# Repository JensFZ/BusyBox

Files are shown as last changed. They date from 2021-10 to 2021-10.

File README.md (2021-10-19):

# BusyBox

In diesen Projekt geht es darum, dass man einen Status einer Website abfragt und, je nach rückgabe, eine grüne oder rote LED Schaltet.

der Web API Code wird demnächst auch hier noch hochgeladen

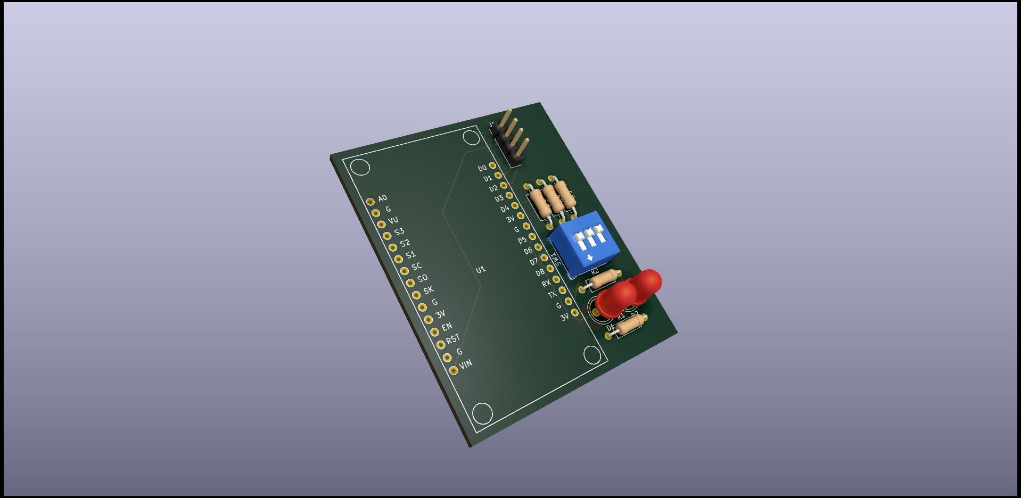
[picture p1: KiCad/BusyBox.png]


## Einrichtung Arduino IDE

- zusützliche Boardverwalter URL: http://arduino.esp8266.com/stable/package_esp8266com_index.json
- über den Boardverwalter nun das Board "esp8266" suchen und installieren
- Als Board nun über "Werkzeuge" -> "Board" -> "ESP8266 Boards" -> "NodeMCU 1.0 (ESP-12E Module)" auswählen
- Uploadspeed auf 115200 stellen
- Port auf den entsprechenden COM Port stellen

## Verwendete Hardware
- 1x NodeMCU Lua Amica Modul V2 ESP8266 ESP-12F
- 1x LED Green
- 1x LED Red
- 1x DIP-Switch 2 Slide
- 5x 1k Wiederstand
- optional LCD 16x2 i2c

## Contributing
Pull requests sind wilkommen. Bei größeren Änderungen eröffnen Sie bitte zunächst ein Issue, um zu besprechen, was Sie ändern möchten.

## License
[MIT](https://choosealicense.com/licenses/mit/)

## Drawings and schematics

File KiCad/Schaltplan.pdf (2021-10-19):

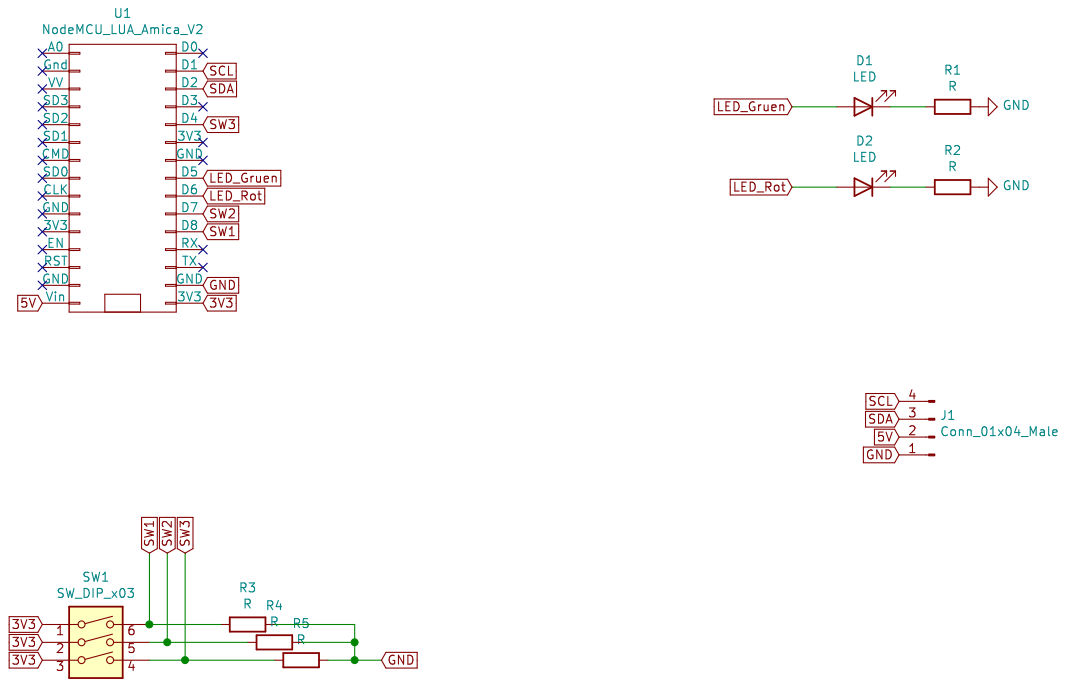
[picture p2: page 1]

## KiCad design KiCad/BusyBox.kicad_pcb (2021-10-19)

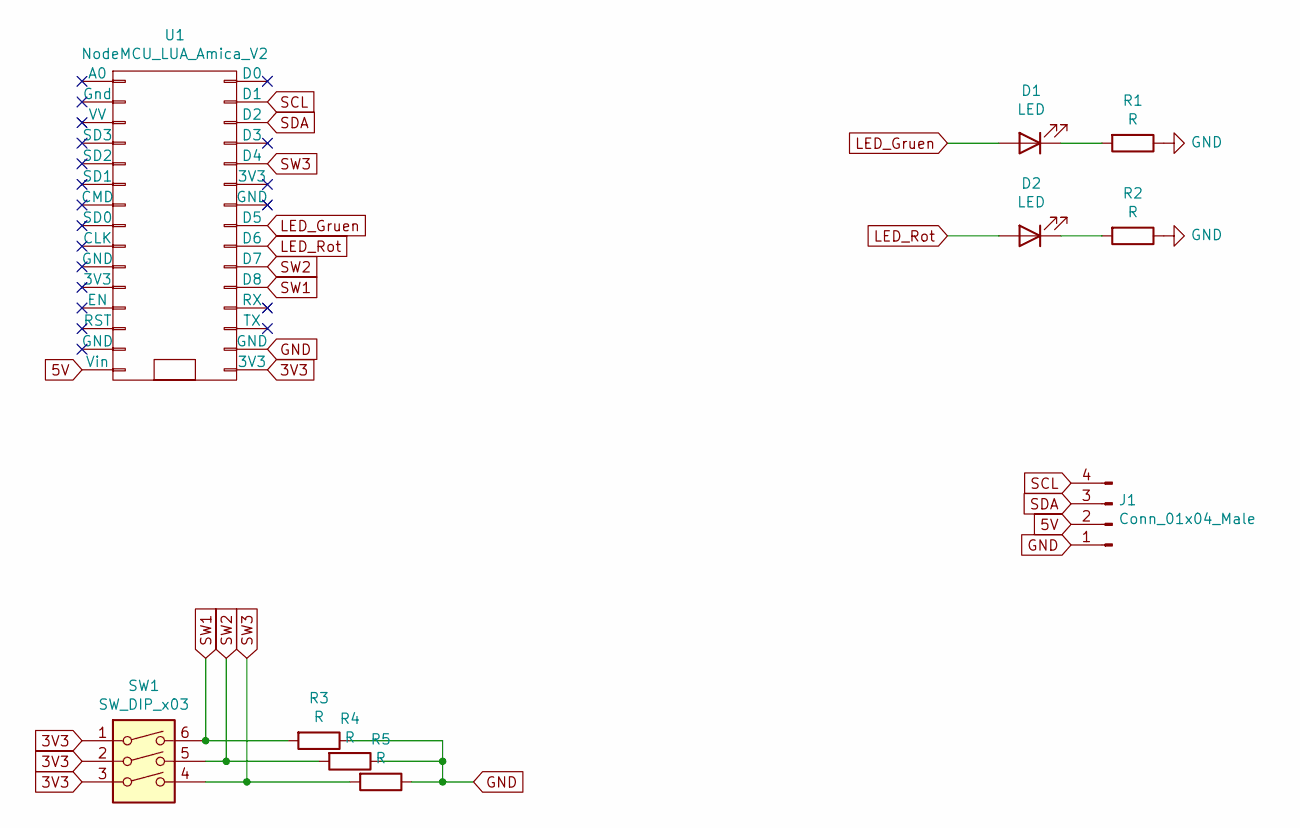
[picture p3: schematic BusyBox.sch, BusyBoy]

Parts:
D1, D2: LED; LED_D5.0mm
J1: Conn_01x04_Male; PinHeader_1x04_P2.54mm_Vertical
R1, R2, R3, R4, R5: R; R_Axial_DIN0207_L6.3mm_D2.5mm_P10.16mm_Horizontal
SW1: SW_DIP_x03; SW_DIP_SPSTx03_Slide_9.78x9.8mm_W7.62mm_P2.54mm
U1: NodeMCU_LUA_Amica_V2; NodeMCU-LoLinV3

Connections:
3V3: SW1.1, SW1.2, SW1.3, U1.16 (3V3)
5V: J1.2, U1.15 (Vin)
GND: J1.1, R1.1, R2.1, R3.1, R4.1, R5.1, U1.17 (GND)
LED_Gruen: D1.2 (A), U1.23 (D5)
LED_Rot: D2.2 (A), U1.22 (D6)
unnamed: D1.1 (K), R1.2
unnamed: D2.1 (K), R2.2
SCL: J1.4, U1.29 (D1)
SDA: J1.3, U1.28 (D2)
SW1: R3.2, SW1.6, U1.20 (D8)
SW2: R4.2, SW1.5, U1.21 (D7)
SW3: R5.2, SW1.4, U1.26 (D4)

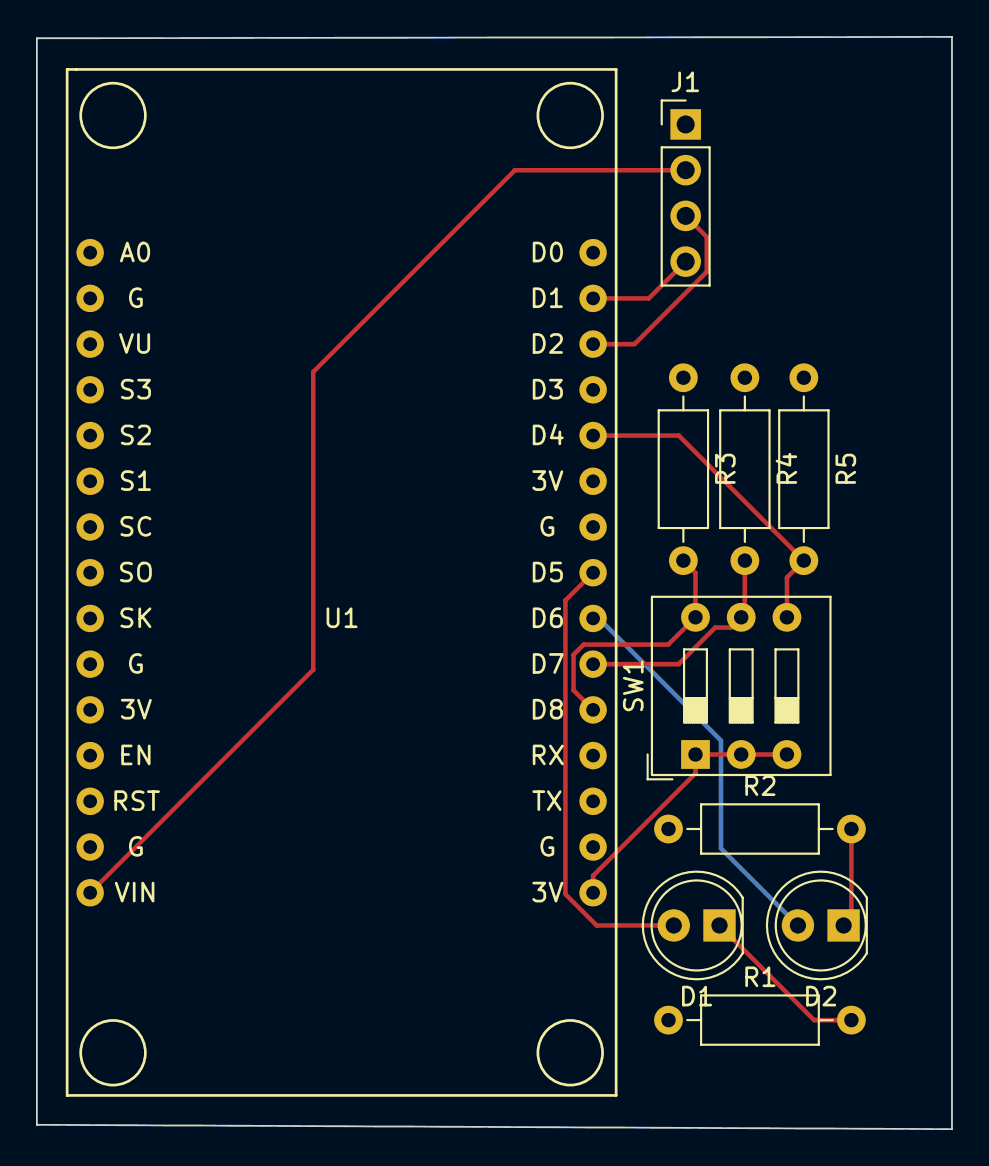
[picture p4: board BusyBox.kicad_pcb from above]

Board: 2 copper layers, 50.8 x 60.7 mm, 10 parts (0 on the bottom side), 12 nets.

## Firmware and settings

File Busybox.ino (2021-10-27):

#include <ESP8266WiFi.h>
#include <ESP8266HTTPClient.h>
#include <HttpClient.h>
#include <ArduinoJson.h>
#include <LiquidCrystal_I2C.h>
#include "config.h"

//const char fingerprint[] PROGMEM = "D7 FB 27 3B A9 97 C9 10 8F 58 95 30 DE B6 03 5B BD D3 66 1a";

#define ledRedPin D6
#define ledGreenPin D5

#define dip3 D8
#define dip2 D7
#define dip1 D4

#define switchState D3

LiquidCrystal_I2C lcd(0x27,16,2); 
WiFiClient wifiClient;
void setup() {
  Serial.flush();

  lcd.init();
  lcd.backlight();
  
  lcd.setCursor(0,0);
  lcd.print("Init");
  
  // put your setup code here, to run once:

  pinMode(LED_BUILTIN, OUTPUT);     // Initialize the LED_BUILTIN pin as an output
  digitalWrite(LED_BUILTIN, LOW);   // Turn the LED on (Note that LOW is the voltage level

  pinMode(ledRedPin, OUTPUT); //Declare Pin mode
  digitalWrite(ledRedPin, LOW); //Declare Pin mode
  
  pinMode(ledGreenPin, OUTPUT); //Declare Pin mode
  digitalWrite(ledGreenPin, LOW); //Declare Pin mode

  pinMode(dip3, INPUT);
  pinMode(dip2, INPUT);
  pinMode(dip1, INPUT);
  
  pinMode(switchState, INPUT);

  //attachInterrupt(digitalPinToInterrupt(switchState), callhttpSwitch, RISING);
  

//  client.setInsecure();
  Serial.begin(115200);
  Serial.println("Awake");

  Serial.print("Connecting to WiFi: ");
  Serial.println(ssid);

  lcd.setCursor(0,0);
  lcd.print("Connecting to:");
  lcd.setCursor(0,1);
  lcd.print(ssid);

  WiFi.mode(WIFI_STA);
  WiFi.begin(ssid, password);

  while (WiFi.status() != WL_CONNECTED) {
    Serial.print(".");
    delay(500);
  }

  Serial.println("");
  Serial.println("Connected!");
  Serial.println("IP address: ");
  Serial.println(WiFi.localIP()); 

  delay(500);
  lcd.clear();
  lcd.setCursor(0,0);
  lcd.print("IP:");
  lcd.setCursor(0,1);
  lcd.print(WiFi.localIP());
  delay(1500);
  lcd.clear();
  lcd.setCursor(0,0);
  lcd.print("ID");

}

bool buttonPressed = false;

bool aktiv = true;

int lastUserID = -1;
bool lastBacklight = true;

unsigned int UserID = 0;

 
void loop() {
  UserID = (digitalRead(dip3) << 2) + (digitalRead(dip2) << 1) + (digitalRead(dip1));

    if(UserID > 0) {
      if(lastUserID != UserID) {
        printUserID();
        lastUserID = UserID;
      }
      
      if(callAktiv()) {
        if(!lastBacklight) {
          lcd.backlight();
          lastBacklight = true;
          lcd.clear();
          lcd.setCursor(0,0);
          lcd.print("ID");
          printUserID();

        }
        callBusy();
        delay(1000);
      } else {
        if(lastBacklight) {
          lcd.noBacklight();
          lcd.clear();
          lastBacklight = false;
        }
        digitalWrite(ledGreenPin, LOW);   //Turn the LED off
        digitalWrite(ledRedPin, LOW);   //Turn the LED off

        delay(30000);
      }
    } else {
      lcd.setCursor(0,1);
      lcd.print("Keine UserID");
      Serial.println("Keine UserID");
      
      delay(10000);
    }
}

void callhttpSwitch() {
  Serial.println("Button");
};

void printUserID() {
  lcd.setCursor(0,1);
  lcd.print("   ");
  lcd.setCursor(0,1);
  lcd.print(UserID);
}


bool callAktiv() {
  Serial.println("callAktiv");
  int err =0;
  HTTPClient http;
  
  String serverPath = serverNameAktiv + UserID;
  Serial.println(serverPath);
  
  http.begin(wifiClient, serverPath);
  int httpResponseCode = http.GET();
  if (httpResponseCode>0) {
    Serial.print("HTTP Response code: ");
    Serial.println(httpResponseCode);
    String payload = http.getString();
    Serial.println(payload);

    const size_t capacity = JSON_ARRAY_SIZE(5) + 5*JSON_OBJECT_SIZE(2) + JSON_OBJECT_SIZE(3) + 200;
    DynamicJsonDocument doc(capacity);
    deserializeJson(doc, payload);
    String Aktiv = doc["Aktiv"];
    Serial.println(Aktiv);
    return Aktiv == "true";
  }

  return false;
}

void callBusy(){
  int err =0;
  HTTPClient http;
  Serial.println(String("UserID: ") + UserID);
  String serverPath = serverNameBusy + UserID;

  Serial.println(serverPath);
  http.begin(wifiClient, serverPath);

  int httpResponseCode = http.GET();
  if (httpResponseCode>0) {
    Serial.print("HTTP Response code: ");
    Serial.println(httpResponseCode);
    String payload = http.getString();
    Serial.println(payload);

    const size_t capacity = JSON_ARRAY_SIZE(5) + 5*JSON_OBJECT_SIZE(2) + JSON_OBJECT_SIZE(3) + 200;
    DynamicJsonDocument doc(capacity);
    deserializeJson(doc, payload);

    String amTelefon = doc["amTelefon"];
    Serial.println("amTelefon: " + amTelefon);
    if(amTelefon == "false") {
      digitalWrite(ledGreenPin, HIGH);   //Turn the LED off
      digitalWrite(ledRedPin, LOW);   //Turn the LED off
  
      lcd.setCursor(3,0);
      lcd.print("      ");
      lcd.setCursor(3,1);
      lcd.print("            ");
      
    } else if(amTelefon == "true"){
      digitalWrite(ledGreenPin, LOW);   //Turn the LED off
      digitalWrite(ledRedPin, HIGH);   //Turn the LED off
  
      char Zeit[20];
      int Total = doc["seit"];
      int Tage = Total / 86400;
      Total = Total % 86400;
      int Stunden = Total / 3600;
      Total = Total % 3600;
      int Minuten = Total / 60;
      int Sekunden = Total % 60;
      
      Serial.println("Tage: " + String(Tage));
      Serial.println("Stunden: " + String(Stunden));
      Serial.println("Minuten: " + String(Minuten));
      Serial.println("Sekunden: " + String(Sekunden));
  
      if(Tage > 0) {
        sprintf(Zeit, "%01d:%02d:%02d:%02d", Tage, Stunden, Minuten, Sekunden);
      } else if(Stunden > 0) {
        sprintf(Zeit, "%02d:%02d:%02d", Stunden, Minuten, Sekunden);
      } else {
        sprintf(Zeit, "%02d:%02d", Minuten, Sekunden);
      }
  
      lcd.setCursor(3,0);
      lcd.print("| Zeit");
      lcd.setCursor(3,1);
      lcd.print("| " + String(Zeit));
    
    }
        
  } else {
    Serial.print("Error code: ");
    Serial.println(httpResponseCode);
  }
  http.end();
}

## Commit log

2021-10-14 Schaltplan erstellt - WIP!
    [BusyBox.sch]
2021-10-19 Schaltplan und Platine designed
    [BusyBox-B_Cu.gbr, BusyBox-B_Mask.gbr, BusyBox-B_Paste.gbr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]
2021-10-19 Code erstellt und angepasst
2021-10-19 BOM erstellt
2021-10-20 switch eingebaut -> noch nicht getestet! API muss true oder Fals für amTelefon geben. somit werden timeouts / Probleme mit der Api nicht als am Telefon interpretiert
    [Busybox.ino]
